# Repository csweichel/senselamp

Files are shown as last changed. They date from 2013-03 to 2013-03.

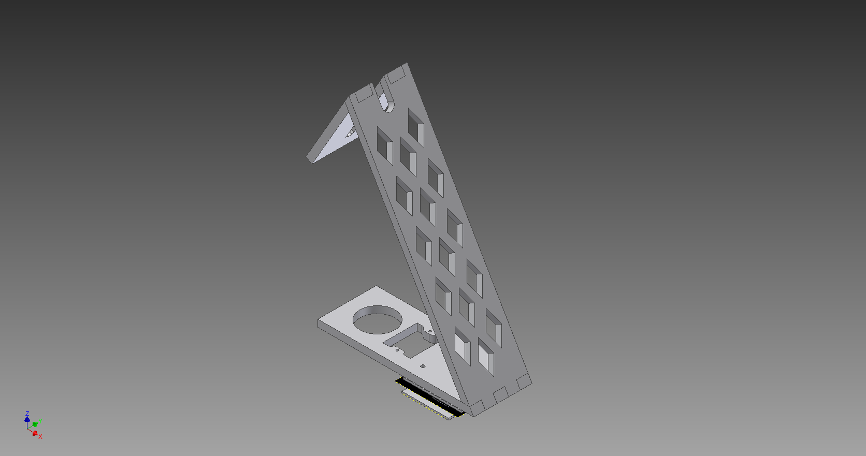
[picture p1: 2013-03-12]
frame/AngledFrame/WithoutInventor/Lamp.png

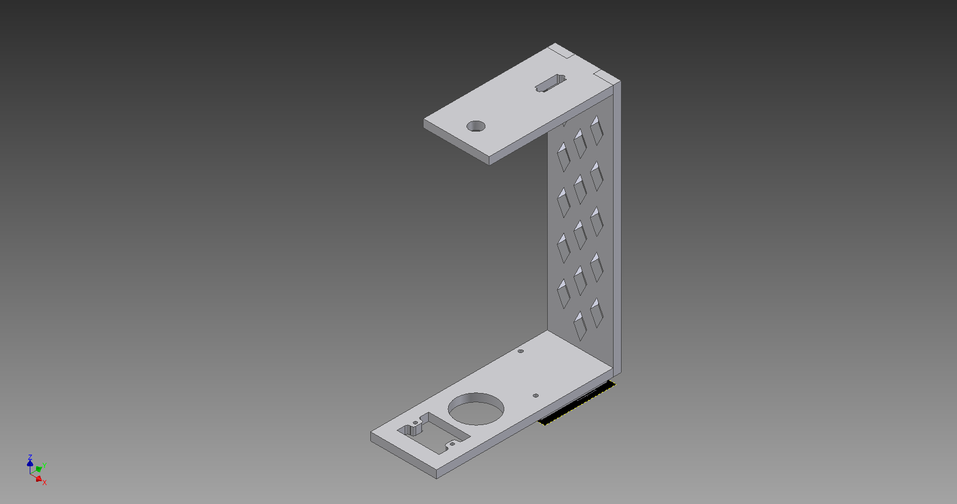
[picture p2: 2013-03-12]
frame/RectangularFrame/WithoutInventor/Lamp.png

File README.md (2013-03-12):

SenseLamp
============================

SenseLamp is a drop-in lampshade replacement that can remotely turn the light on and off, runs Linux, is WiFi connected and has a bunch of sensors:
 * __Temperature and humidity sensor:__ recommended DHT11/DHT12 or anything pin-compatible
 * __PIR motion sensor:__ typically HC-SR501 PIR, easily found on eBay
 * __LDR light sensor:__ any light-dependent resistor works as long as the voltage divider is adjusted

In addition to a custom PCB, the SenseLamp is powered by a [TL WR703N](http://wiki.openwrt.org/toh/tp-link/tl-wr703n) WiFi router, which can be bought for cheap of eBay. The total power consumption is around 120-150mA/5V.

## How does this thing look like?
Images can be found in my blog: [32leav.es](http://32leav.es/?tag=senselamp)

## What's in this repository?
 * <tt>board</tt> the [Eagle](http://www.cadsoftusa.com/) files for the custom PCB going on top of the WR703N
 * <tt>frame</tt> AutoDesk Inventor sources and DXF files for two laser cut frame variants. The RectangularFrame could be ordered from [Ponoko](https://www.ponoko.com/), while the AngeledFrame requires some advanced laser-cutting techniques.
 * <tt>msp430</tt> contains the firmware for the MSP430 controlling the sensors - written using [Energia](https://github.com/energia/Energia/)

## What is __NOT__ in this repository?
The OpenWRT user-land to actually speak with the sensors. I use SenseLamps in combination with [busfarhn](https://github.com/32leaves/busfahrn), and have some code there that might help: [scripts/native_clients](https://github.com/32leaves/busfahrn/tree/master/scripts/native_clients).

## How do I build my own?
1. Get all the parts: a TL-WR703N, a TI Launchpad incl. its MSP430G2553, all the sensors and parts needed for the board (see schematics) and some form of relay module.
2. Solder thin wires to the serial testpads of the WR703N - see existing sources how to do this: [here](http://forums.openpilot.org/blog/52/entry-92-unbrick-wr703n-wifi-router/), [here](http://www.designspark.com/blog/hacking-the-tp-link-tl-wr703n) and [here](http://www.instructables.com/id/TL-WR703N-serial-port/). In the end you should have two wires that you could solder onto the SenseLamp board.
3. Solder all components on the SenseLamp board.
4. Laser-cut a frame or go to town on some tupperware with a Dremel
5. Assemble all components onto the frame
6. Power the whole contraption and play with some commands (have a look at the firmware for what commands there are)
7. Hook it up to your busfarhn installation.

# License - "MIT License"
Copyright (c) 2013 Christian Weichel, 32leaves

Permission is hereby granted, free of charge, to any person obtaining a copy of this software and associated documentation files (the "Software"), to deal in the Software without restriction, including without limitation the rights to use, copy, modify, merge, publish, distribute, sublicense, and/or sell copies of the Software, and to permit persons to whom the Software is furnished to do so, subject to the following conditions:

The above copyright notice and this permission notice shall be included in all copies or substantial portions of the Software.

THE SOFTWARE IS PROVIDED "AS IS", WITHOUT WARRANTY OF ANY KIND, EXPRESS OR IMPLIED, INCLUDING BUT NOT LIMITED TO THE WARRANTIES OF MERCHANTABILITY, FITNESS FOR A PARTICULAR PURPOSE AND NONINFRINGEMENT. IN NO EVENT SHALL THE AUTHORS OR COPYRIGHT HOLDERS BE LIABLE FOR ANY CLAIM, DAMAGES OR OTHER LIABILITY, WHETHER IN AN ACTION OF CONTRACT, TORT OR OTHERWISE, ARISING FROM, OUT OF OR IN CONNECTION WITH THE SOFTWARE OR THE USE OR OTHER DEALINGS IN THE SOFTWARE.

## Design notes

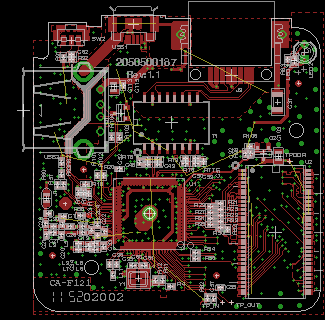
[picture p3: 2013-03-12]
frame/RectangularFrame/board_tlwr703n.png

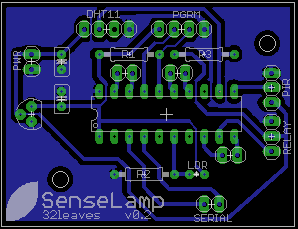
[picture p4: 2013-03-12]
frame/AngledFrame/board.png

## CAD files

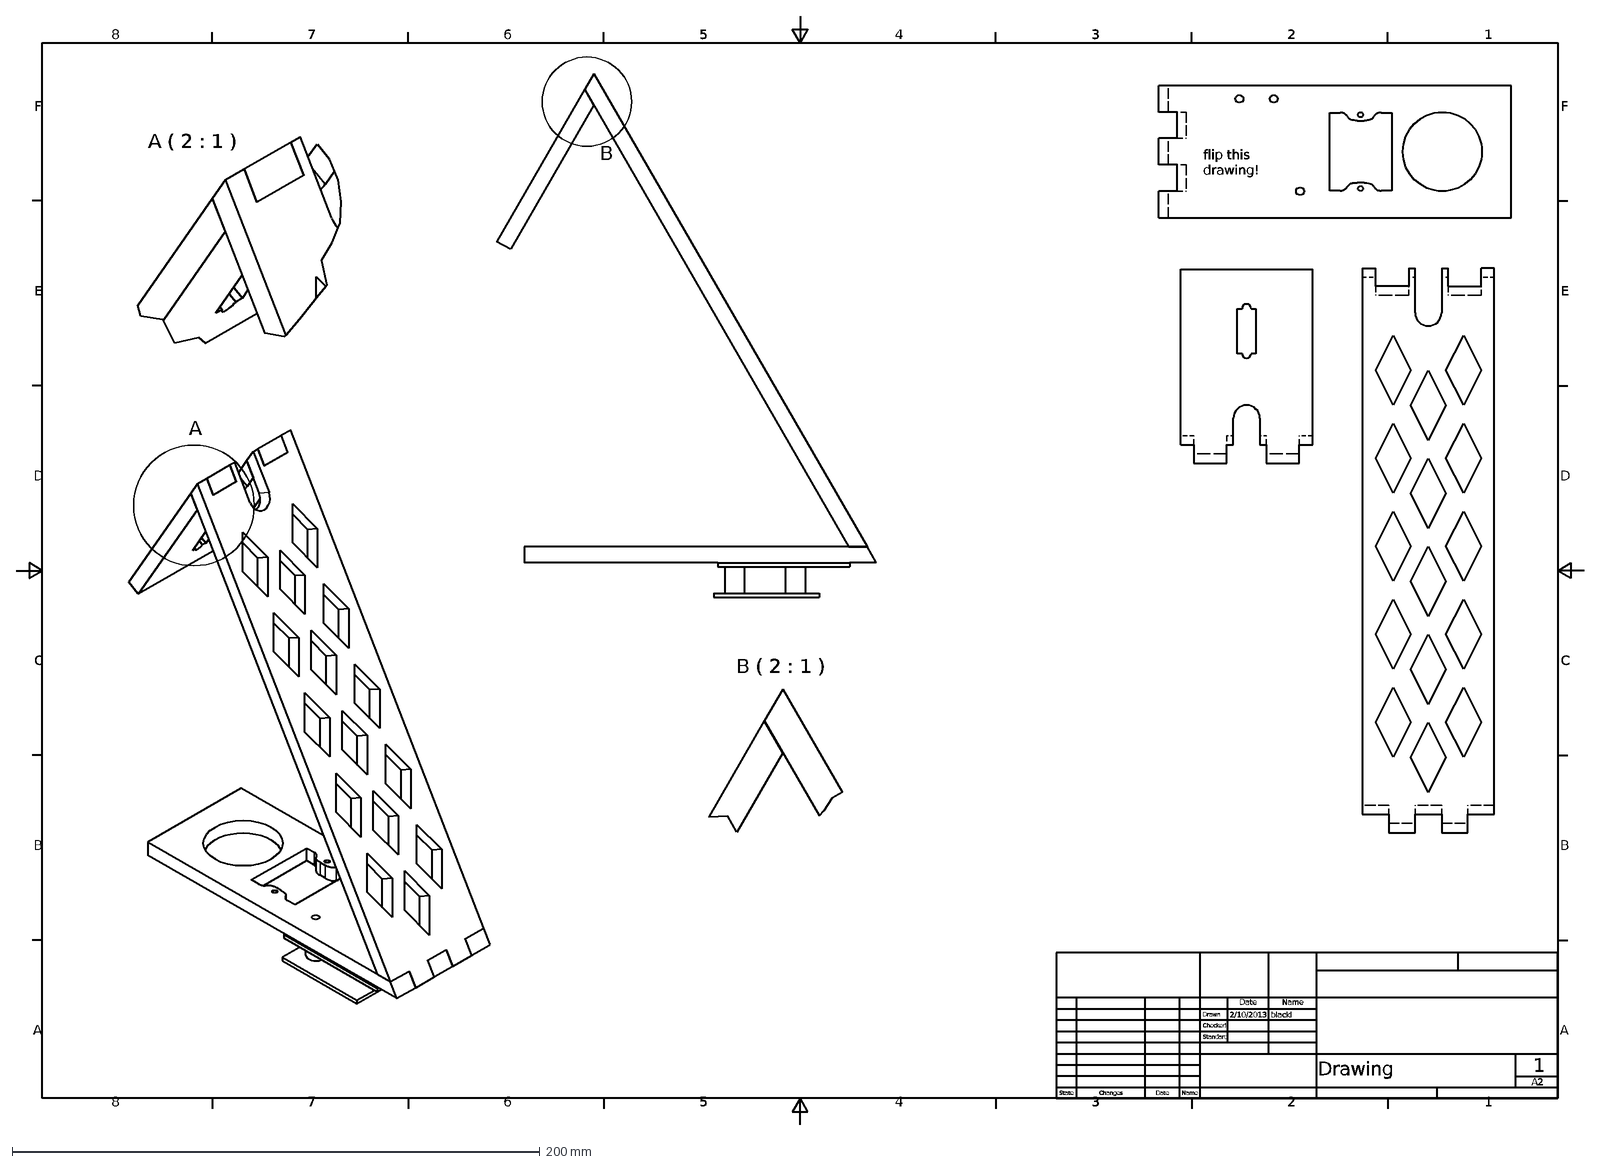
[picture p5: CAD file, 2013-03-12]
frame/AngledFrame/WithoutInventor/Drawing.dxf
1
2
3
4
5
6
7
8
A
B
C
D
E
F
A2
Drawing
2/10/2013
blacki
State
Changes
Date
Name
Drawn
Checked
Standard
A ( 2 : 1 )
B ( 2 : 1 )
flip this drawing!

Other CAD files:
frame/RectangularFrame/WithoutInventor/Drawing.dxf
frame/AngledFrame/Drawing.idw
frame/AngledFrame/Lamp.iam
frame/AngledFrame/PCBSPACER.IPT
frame/AngledFrame/TLwr703n_image.ipt
frame/AngledFrame/TRIANGLELONGLEG.IPT
frame/AngledFrame/TriangleBase.ipt
frame/AngledFrame/TriangleShortLeg.ipt
frame/AngledFrame/board_image.ipt
frame/RectangularFrame/BOTTOM.IPT
frame/RectangularFrame/Back.ipt
frame/RectangularFrame/Drawing.idw
frame/RectangularFrame/Lamp.iam
frame/RectangularFrame/TLwr703n_image.ipt
frame/RectangularFrame/Top.ipt

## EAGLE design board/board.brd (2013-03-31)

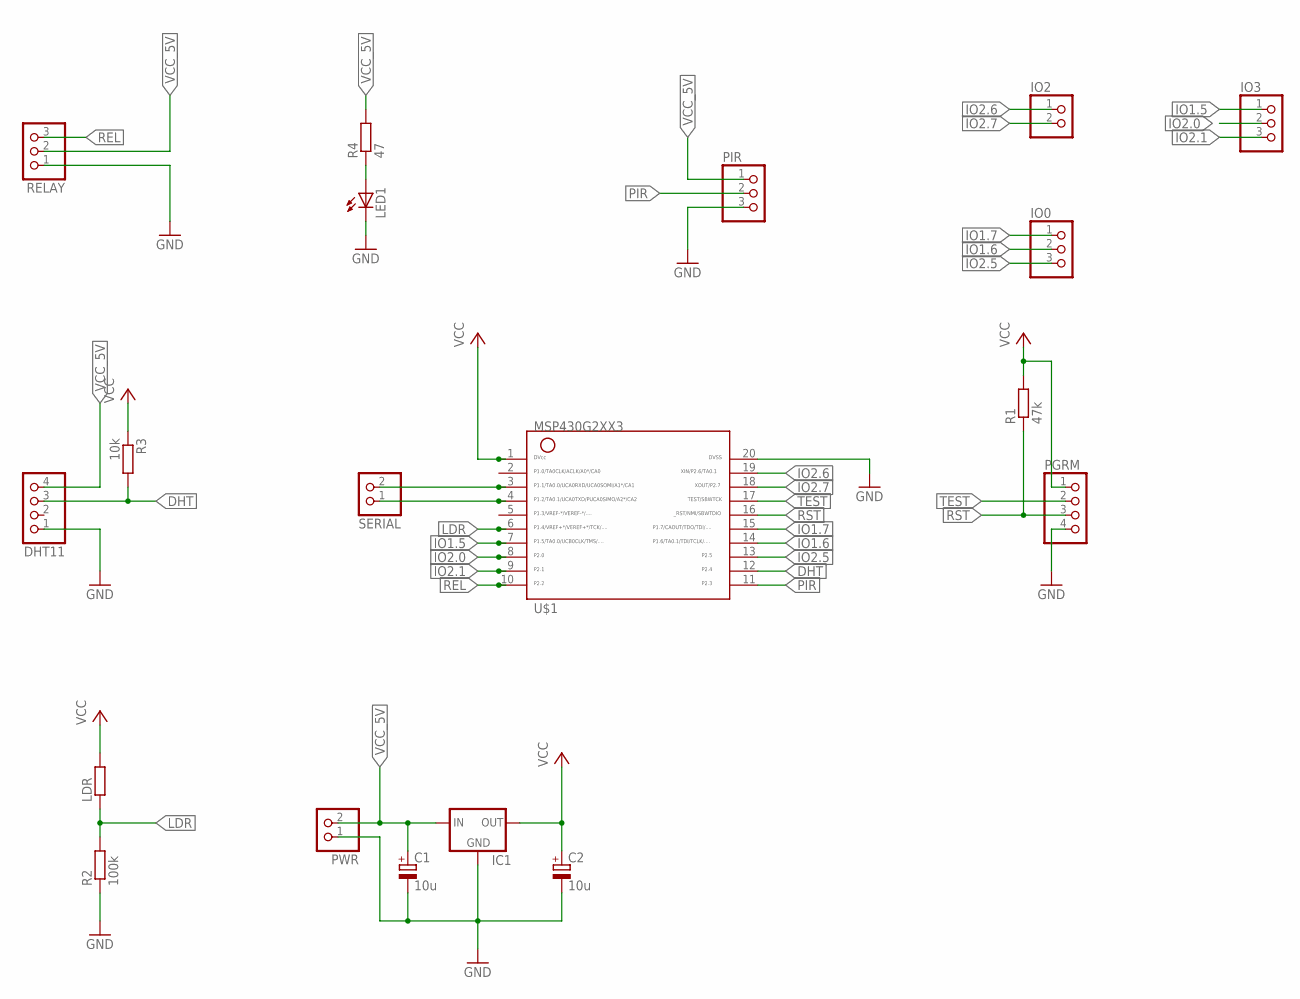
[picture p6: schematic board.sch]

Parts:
C1, C2: 10u; E2,5-5
DHT11: PINHD-1X4; 1X04
IC1: MCP1700TRI; TO92
IO0, IO3: PINHD-1X3; 1X03
IO2: PINHD-1X2; 1X02
LDR: R-EU_0207/5V; 0207/5V
LED1: LED3MM
PGRM: PINHD-1X4; 1X04
PIR: PINHD-1X3; 1X03
PWR: PINHD-1X2; 1X02
R1: 47k; 0207/10
R2: 100k; 0207/10
R3: 10k; 0207/10
R4: 47; 0207/10
RELAY: PINHD-1X3; 1X03
SERIAL: PINHD-1X2; 1X02
U$1: G2XX3---N20; N20

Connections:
DHT: DHT11.3, R3.2, U$1.12
GND: C1.-, C2.-, DHT11.1, IC1.1 (GND), LED1.K (C), PGRM.4, PIR.3, PWR.1, R2.1, RELAY.1, U$1.20
IO1.5: IO3.1, U$1.7
IO1.6: IO0.2, U$1.14
IO1.7: IO0.1, U$1.15
IO2.0: IO3.2, U$1.8
IO2.1: IO3.3, U$1.9
IO2.5: IO0.3, U$1.13
IO2.6: IO2.1, U$1.19
IO2.7: IO2.2, U$1.18
LDR: LDR.1, R2.2, U$1.6
unnamed: LED1.A, R4.1
unnamed: SERIAL.2, U$1.3
unnamed: SERIAL.1, U$1.4
PIR: PIR.2, U$1.11
REL: RELAY.3, U$1.10
RST: PGRM.3, R1.1, U$1.16
TEST: PGRM.2, U$1.17
VCC: C2.+, IC1.3 (OUT), LDR.2, PGRM.1, R1.2, R3.1, U$1.1
VCC_5V: C1.+, DHT11.4, IC1.2 (IN), PIR.1, PWR.2, R4.2, RELAY.2

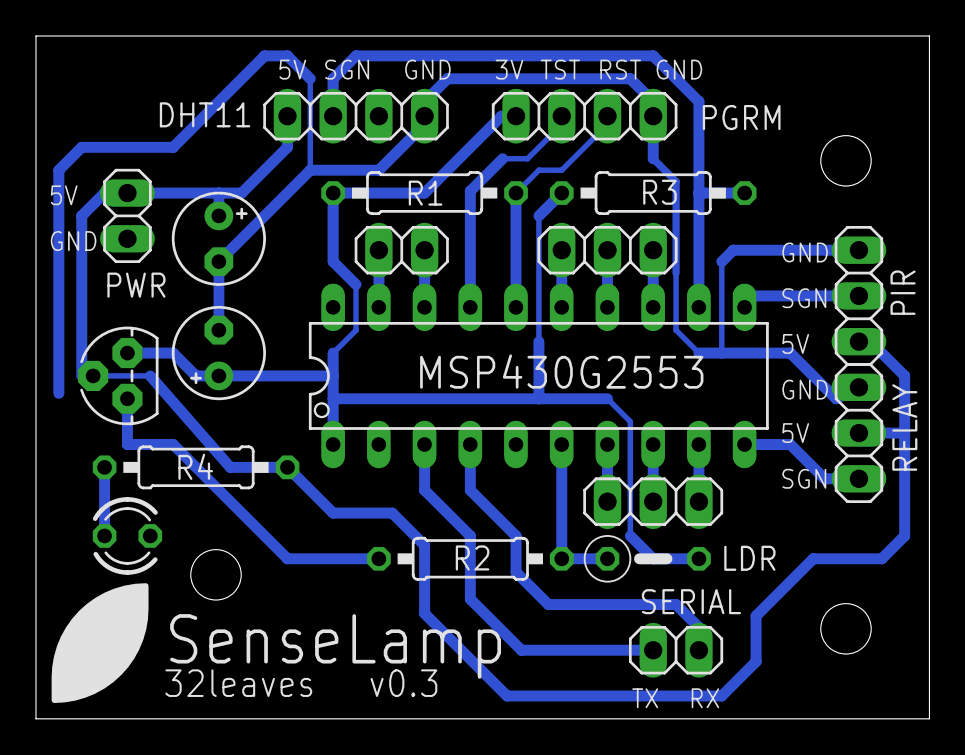
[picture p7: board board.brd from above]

Board: 2 copper layers, 49.6 x 37.9 mm, 19 parts (0 on the bottom side), 20 nets.

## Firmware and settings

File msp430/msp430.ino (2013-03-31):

#define PIN_RELAY 10
#define PIN_PIR   11
#define PIN_DHT   12
#define PIN_LDR   A4
#define LDR_AVG   10
//define NO_LED
#define NO_PREAMBLE
#define USE_DHT22

#ifndef NO_PREAMBLE
#define _PREAMBLE_COUNT 10
#define _PREAMBLE_CHAR  '!'
#endif

#ifndef NO_LED
#define LED_BOOT  GREEN_LED
#define LED_LAMP  RED_LED
#endif

#define DHT_OK                0
#define DHT_ERROR_CHECKSUM   -1
#define DHT_ERROR_TIMEOUT    -2

int buttonState = LOW;
unsigned int buttonDebounce = 0;
int careAboutPIR = 1;

#define MAXTIMINGS 85
int external_readDHT22() {
  uint8_t lastState = HIGH;
  uint16_t counter = 0;
  uint8_t j = 0, i;
  
  uint8_t data[6];
  uint8_t _pin = PIN_DHT;
  uint32_t _lastMillis;
  boolean _lastResult;
  uint32_t _temperature, _humidity;
  
  _temperature = 0;
  _humidity    = 0;
  
  // pull the pin high and wait 250 milliseconds
  digitalWrite(_pin, HIGH);
  delay(250);
  data[0] = data[1] = data[2] = data[3] = data[4] = 0;
  
  // now pull it low for ~20 milliseconds
  pinMode(_pin, OUTPUT);
  digitalWrite(_pin, LOW);
  delay(20);
  
  noInterrupts();
  
  digitalWrite(_pin, HIGH);
  delayMicroseconds(40);
  pinMode(_pin, INPUT);
  
  // read in timings
  for ( i=0; i< MAXTIMINGS; i++) {
    counter = 0;
    while (digitalRead(_pin) == lastState) {
      counter++;
#if defined(__MSP430G2452__) || defined(__MSP430G2553__) || defined(__MSP430G2231__) // LaunchPad specific
      // LaunchPad implementation
      // LaunchPad faster than Arduino
      // 1. replace delayMicroseconds(1) with delayMicroseconds(3)
      // or
      // 2. compare counter to a higher number
      // by energia » Tue Jun 26, 2012 9:24 pm
      // see http://www.43oh.com/forum/viewtopic.php?p=20821#p20821
      delayMicroseconds(3);
#else // other boards - not tested
      delayMicroseconds(1);
#endif
      if (counter == 255) {
        break;
      }
    }
    lastState = digitalRead(_pin);
    
    if (counter == 255) break;
    
    // ignore first 3 transitions
    if ((i >= 4) && (i%2 == 0)) {
      // shove each bit into the storage bytes
      data[j/8] <<= 1;
      
      // 1. replace delayMicroseconds(1) with delayMicroseconds(3)
      // or
      // 2. compare counter to a higher number
      // by energia » Tue Jun 26, 2012 9:24 pm
      // see http://www.43oh.com/forum/viewtopic.php?p=20821#p20821
      //      if (counter > 8)
      if (counter > 6)
        data[j/8] |= 1;
      j++;
    }
  }
  
  interrupts();
  
  #ifdef DEBUG
  Serial.println();
  Serial.print("debug \t");
  Serial.print("bits received \t");
  Serial.println(j, DEC);
  
  Serial.print("debug \t");
  Serial.print(data[0], HEX); 
  Serial.print(", ");
  Serial.print(data[1], HEX); 
  Serial.print(", ");
  Serial.print(data[2], HEX); 
  Serial.print(", ");
  Serial.print(data[3], HEX); 
  Serial.print(", ");
  Serial.print(data[4], HEX); 
  Serial.print(" =? ");
  Serial.println(data[0] + data[1] + data[2] + data[3] & 0xff, HEX);
  
  Serial.print("debug \t");
  Serial.print(" checksum \t");
  Serial.println( (data[4] == ((data[0] + data[1] + data[2] + data[3]) & 0xFF)) ? "ok" : "NO" );
  
  Serial.print("debug \t");
  Serial.print("RH% \t");
  Serial.println(data[0]*256 + data[1], DEC);
  
  Serial.print("debug \t");
  Serial.print("oC \t");
  Serial.println(data[2]*256 + data[3], DEC);
  #endif

  if((data[4] == ((data[0] + data[1] + data[2] + data[3]) & 0xFF))) {
    Serial.print("DHT OK h:");
    Serial.print((data[0]*256 + data[1]) / 10, DEC);
    Serial.print(".");
    Serial.print((data[0]*256 + data[1]) % 10, DEC);
    Serial.print(" t:");
    Serial.print((data[2]*256 + data[3]) / 10, DEC);
    Serial.print(".");
    Serial.print((data[2]*256 + data[3]) % 10, DEC);
    Serial.println();
  }

  // check we read 40 bits and that the checksum matches
  if ((j >= 40) && (data[4] == ((data[0] + data[1] + data[2] + data[3]) & 0xff)) ) {
    
    _temperature = data[2] & 0x7f;
    _temperature *= 256;
    _temperature += data[3];
    if (data[2] & 0x80) _temperature *= -1;
    
    _humidity = data[0];
    _humidity *= 256;
    _humidity += data[1];
    return DHT_OK;
  } else {
    return DHT_ERROR_CHECKSUM;
  }
}

int readDHTBytes(unsigned char* buffer) {
  // send start signal
  pinMode(PIN_DHT, OUTPUT);
  digitalWrite(PIN_DHT, HIGH);
  delay(250);
  digitalWrite(PIN_DHT, LOW);
  delay(18);
  digitalWrite(PIN_DHT, HIGH);
  delayMicroseconds(8);
  pinMode(PIN_DHT, INPUT);

  // wait for LOW response
  {
    int i = 0;
    while(digitalRead(PIN_DHT) == LOW) {
      if(i++ >= 8) return DHT_ERROR_TIMEOUT;
      delayMicroseconds(10);
    }
  }
  // wait for HIGH response
  {
    int i = 0;
    while(digitalRead(PIN_DHT) == HIGH) {
      if(i++ >= 8) return DHT_ERROR_TIMEOUT;
      delayMicroseconds(10);
    }
  }

  // read five bytes
  int bite = 0;
  for(bite = 0; bite < 5; bite++) {
    buffer[bite] = 0;

    int bit = 0;
    for(bit = 0; bit < 8; bit++) {
      // wait until signal goes high
      while(digitalRead(PIN_DHT) != HIGH) nop();// delayMicroseconds(1);

      // if signal is still high, this bit is a 1
      delayMicroseconds(30);
      if(digitalRead(PIN_DHT) == HIGH) {
        buffer[bite] |= 1 << (7 - bit);
        while(digitalRead(PIN_DHT) != LOW) nop();//delayMicroseconds(1);
        //delayMicroseconds(10);
      }
    }
  }
  
  Serial.print("DHT DUMP"); for(bite = 0; bite < 5; bite++) { Serial.print(" 0x"); Serial.print(buffer[bite], HEX); }; Serial.println();
  
  unsigned char checksum = 0;
  for(bite = 0; bite < 4; bite++) checksum += buffer[bite];
  if(checksum != buffer[4]) {
    return DHT_ERROR_CHECKSUM;
  }
  
  return DHT_OK;
}

int readDHT11(int* humidity, int* temperature) {
  unsigned char buffer[5];
  noInterrupts();
  int result = readDHTBytes(buffer);
  interrupts();
  if(result != DHT_OK) return result;

  *(humidity + 0)    = buffer[0];
  *(humidity + 1)    = buffer[1];
  *(temperature + 0) = buffer[2];
  *(temperature + 1) = buffer[3];
  return DHT_OK;
}

int readDHT22(float* humidity, float* temperature) {
  unsigned char buffer[5];
  noInterrupts();
  int result = readDHTBytes(buffer);
  interrupts();

  *(humidity)    = word(buffer[0], buffer[1]) * 0.1;
  *(temperature) = (buffer[2] & 0x80 ? -1 : 1) * word(buffer[2], buffer[3]) * 0.1;
  return result;
}

#ifdef USE_DHT22
void updateTemperatureReading() {
  external_readDHT22();
}

/* IF I USED MY OWN IMPLEMENTATION
void updateTemperatureReading() {
  float humidity, temperature;
  
  int success = readDHT22(&humidity, &temperature);

  Serial.print("DHT ");
  switch(success) {
    case DHT_OK: Serial.print("OK "); break;
    case DHT_ERROR_CHECKSUM: Serial.print("ERR_CHECKSUM "); break;
    case DHT_ERROR_TIMEOUT:  Serial.print("ERR_TIMEOUT "); break;
  }
  Serial.print("h:"); Serial.print(humidity);
  Serial.print(" t:"); Serial.print(temperature);
  Serial.println();
}
*/
#else
void updateTemperatureReading() {
  int humidity[2], temperature[2];
  
  int success = readDHT11(&humidity, &temperature);
  if(success == DHT_OK) {
    Serial.print("DHT h:"); Serial.print(humidity[0]); Serial.print("."); Serial.print(humidity[1]);
    Serial.print(" t:"); Serial.print(temperature[0]); Serial.print("."); Serial.print(temperature[1]);
    Serial.println();
  } else if(success == DHT_ERROR_TIMEOUT) {
    Serial.println("DHT ERROR TIMEOUT");
  } else if(success == DHT_ERROR_CHECKSUM) {
    Serial.println("DHT ERROR CHECKSUM");
  }
}
#endif

void updateLDRReading() {
  unsigned long avg = 0;
  for(int i = 0; i < LDR_AVG; i++) {
    avg += analogRead(PIN_LDR);
  }
  Serial.print("LDR l:"); Serial.println(avg / LDR_AVG);
}

void turnLampOn() {
  digitalWrite(PIN_RELAY, LOW);
  #ifndef NO_LED
  digitalWrite(LED_LAMP, HIGH);
  #endif
}

void turnLampOff() {
  digitalWrite(PIN_RELAY, HIGH);  
  #ifndef NO_LED
  digitalWrite(LED_LAMP, LOW);
  #endif
}

void setup() {
  Serial.begin(115200);

  pinMode(PIN_RELAY, OUTPUT);
  digitalWrite(PIN_RELAY, HIGH);
  
  pinMode(PIN_PIR, INPUT);
  pinMode(PIN_DHT, OUTPUT);

  #ifndef NO_LED
  pinMode(LED_BOOT, OUTPUT);  
  digitalWrite(LED_BOOT, HIGH);
  pinMode(LED_LAMP, OUTPUT);  
  digitalWrite(LED_LAMP, LOW);
  #endif
  
  Serial.println("READY");
}

#ifndef NO_PREAMBLE
int preambleCount = _PREAMBLE_COUNT;
#endif

void loop() {
  // if we get a valid byte, read analog ins:
  if (Serial.available() > 0) {
    // get incoming byte:
    char inByte = Serial.read();

#ifndef NO_PREAMBLE
    if(inByte == _PREAMBLE_CHAR) {
      if(preambleCount > 0) preambleCount --;
    } else if(preambleCount == 0) {
#endif
      switch(inByte) {
        case 't': updateTemperatureReading(); break;
        case 'r': updateLDRReading(); break;
        case 'L': turnLampOn(); break;
        case 'l': turnLampOff(); break;
        case 'P': careAboutPIR = 1; break;
        case 'p': careAboutPIR = 0; break;
        case 'a': Serial.println("ALIVE"); break;
      }
#ifndef NO_PREAMBLE
      preambleCount = _PREAMBLE_COUNT;
    }
#endif
    inByte = 0;
  }
  
  int newButtonState = digitalRead(PIN_PIR);
  if(careAboutPIR && newButtonState != buttonState && newButtonState == HIGH && abs(millis() - buttonDebounce) > 100) {
    Serial.print("PIR b:");
    Serial.print(newButtonState);
    Serial.println();
    buttonDebounce = millis();
  }
  buttonState = newButtonState;
}

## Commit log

2013-03-13 fixed some space issues of the v0.1 board
    [board.brd, board.sch]
2013-03-18 finished the v02 board
    [board.brd, board.sch]
2013-03-31 updated the board and firmware to a new revision / pin mapping is now correct and installing a PIR sensor is a lot easier
    [board.brd, board.sch]
